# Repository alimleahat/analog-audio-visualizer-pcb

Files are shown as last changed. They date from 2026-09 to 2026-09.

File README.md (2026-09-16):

# Analog Audio Visualizer PCB

A three-band audio visualizer built for **ELEC2101 Electronic Circuits and Systems Design**. It separates audio into bass, midrange, and treble, with an LED responding to each band.

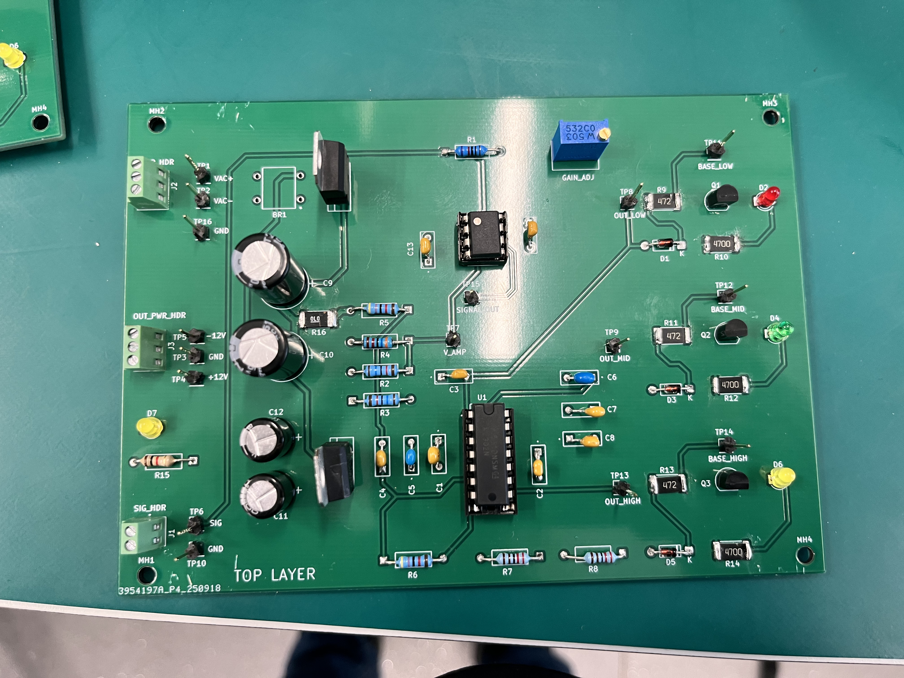
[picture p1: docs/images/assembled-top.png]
Assembled audio visualizer PCB


## My contribution

Following the course guide and reference circuit, I completed the schematic in KiCad, assigned component footprints, laid out and routed the PCB, prepared the manufacturing files, assembled the board, and tested it in the lab.

The project gave me practical experience with analog circuits, two-layer PCB layout, through-hole and surface-mount soldering, and electrical measurements.

## How it works

The audio input passes through an adjustable amplifier, then three filters separate the low, middle, and high frequencies. Transistor circuits drive the corresponding LEDs. The circuit uses LM2904 and LM2902 op-amps and a dual ±12 V supply.

[View the schematic](docs/images/schematic.png) · [View the PCB layout](docs/images/pcb-layout.png)

## Assembly and testing

The board was assembled and tested using a regulated bench supply connected through J3. The recorded supply measurements were **+11.99 V** and **−12.03 V**. The lab checklist records all three LEDs responding to audio and the sensitivity adjustment working.

The bridge rectifier BR1 was unavailable, so the AC-input power-supply section was not tested. The treble LED is yellow instead of the blue LED specified in the design.

[Solder-side photo](docs/images/solder-side.png) · [Surface-mount detail](docs/images/smd-detail.png) · [Measurement photos and test notes](docs/testing.md)

## Open the design

Open [`hardware/audiovisualiser.kicad_pro`](hardware/audiovisualiser.kicad_pro) in **KiCad 9** with the standard symbol and footprint libraries installed. The project includes the editable schematic and PCB layout.

The folders contain:

- **`hardware/`** — KiCad project, schematic, and PCB.
- **`manufacturing/`** — Gerber and drill files for fabrication, a bill of materials, and component positions.
- **`docs/`** — design images, assembly photos, measurements, and design-check reports.

The latest KiCad checks report no electrical or PCB layout violations under the saved rules, and no unconnected items. Four comparison warnings identify mounting holes that appear only on the PCB. Details are in the [testing notes](docs/testing.md).

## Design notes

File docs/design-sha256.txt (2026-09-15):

d43a5ad52d6238cfd297c0390aba6e84c12491bfbb42c92468e123850f972aae  hardware/audiovisualiser.kicad_pcb
11a3e94168e5f908d9af25af031c0f9f0a650db64b1d5642f39403e3dbae1e51  hardware/audiovisualiser.kicad_pro
699c0b7c9d165394a2f6ad1a235572f3e88ec57767753e0e1b9193906fe388a9  hardware/audiovisualiser.kicad_sch
56e890d3f30cbfee17a181a69a6859d38080b0e7b6440230e2523ef3031b595b  manufacturing/gerbers/audiovisualiser-B_Cu.gbr
b3edec788258d4f6de82463fa68dd532487a897ee7c1164198f9244877f3723b  manufacturing/gerbers/audiovisualiser-B_Mask.gbr
3db5783e143c3a7090b456dbd70b5f65db10d94b7363bcfdbad7da6e1dbb668b  manufacturing/gerbers/audiovisualiser-B_Silkscreen.gbr
cdbf6ed5389bc9ae697716cc27e2d69105f45a44620da87fb1bf32727c460968  manufacturing/gerbers/audiovisualiser-Edge_Cuts.gbr
14875b5e7e3f8ffb195601ec47e5f753f74b633e8d50d9912a69eebf286eb574  manufacturing/gerbers/audiovisualiser-F_Cu.gbr
0dd54d515c6167a6fd7fc06f26bf98b8b54d1db28c1bfb878f05ad543f4662b6  manufacturing/gerbers/audiovisualiser-F_Mask.gbr
acfe5b5dd1af43d6daa099b551af098ea3adf2971c16712e91b3fa432e4e91e0  manufacturing/gerbers/audiovisualiser-F_Silkscreen.gbr
f37c09cf444785ee8dca576edfb6f33e4edd3a44a8568f85b55a7a8c0175424d  manufacturing/gerbers/audiovisualiser-NPTH.drl
87c2988971aea0b9ab081e4a7189159ee5fceac178d744cfe9fef5f88cfd54ae  manufacturing/gerbers/audiovisualiser-PTH.drl
732ebaa7cd275ef8b9e11f3401f31154eaca13fc0503ec177f53244ad57ac680  manufacturing/gerbers/audiovisualiser-job.gbrjob
2de11d1e49a75330ba2134e22420dceb4e55c76b61dfe5de430449ad1b904d96  manufacturing/bill-of-materials.csv
264a6dbcaaf517e89931273f5c0e9ae222f43909895c9295ed0664edde9b2d73  manufacturing/component-positions.csv

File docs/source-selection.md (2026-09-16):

# Source selection

## Selected design

The working `audiovisualiser` directory, the Week 4 submission, and `AudioVisualiserFiles` contain byte-identical schematic and PCB files. The working directory also contains the matching KiCad project settings, which are included so the saved design rules travel with the schematic and board.

The seven Gerber files match the Week 4 production archive byte-for-byte. Plated and non-plated drill files, the Gerber job file, the BOM, and component positions come from the same working project. Manufacturing files are historical exports; they were not regenerated during portfolio preparation.

## Selected build evidence

The extracted Week 11 folder matches the final Week 11 ZIP. The archive with the `2.zip` suffix differs in its README and test checklist; the final extracted folder was used because it includes the explicit BR1 omission and bench-supply test qualification.

Three assembly images were extracted from the final assembly-photo PDF. The power-on and positive/negative rail photos come from the final testing folder. Image content is preserved.

## Excluded material

Videos, duplicate submission archives, autosaves, backup ZIPs, local KiCad state, repeated photo PDFs, and student-number submission filenames are omitted. The original test checklist contains general instructions and a broad pass statement that could obscure the untested AC power path; its relevant outcomes are summarized in `testing.md`.

The course manual and supplied reference PDF were used to establish project context. They are not republished. The public schematic is the author's KiCad capture of the guided reference design.

## Original files

The source archive remains untouched. Project files, manufacturing exports, and selected standalone images were copied; assembly photos were extracted from the existing PDF. Documentation and new KiCad check reports were added for this repository.

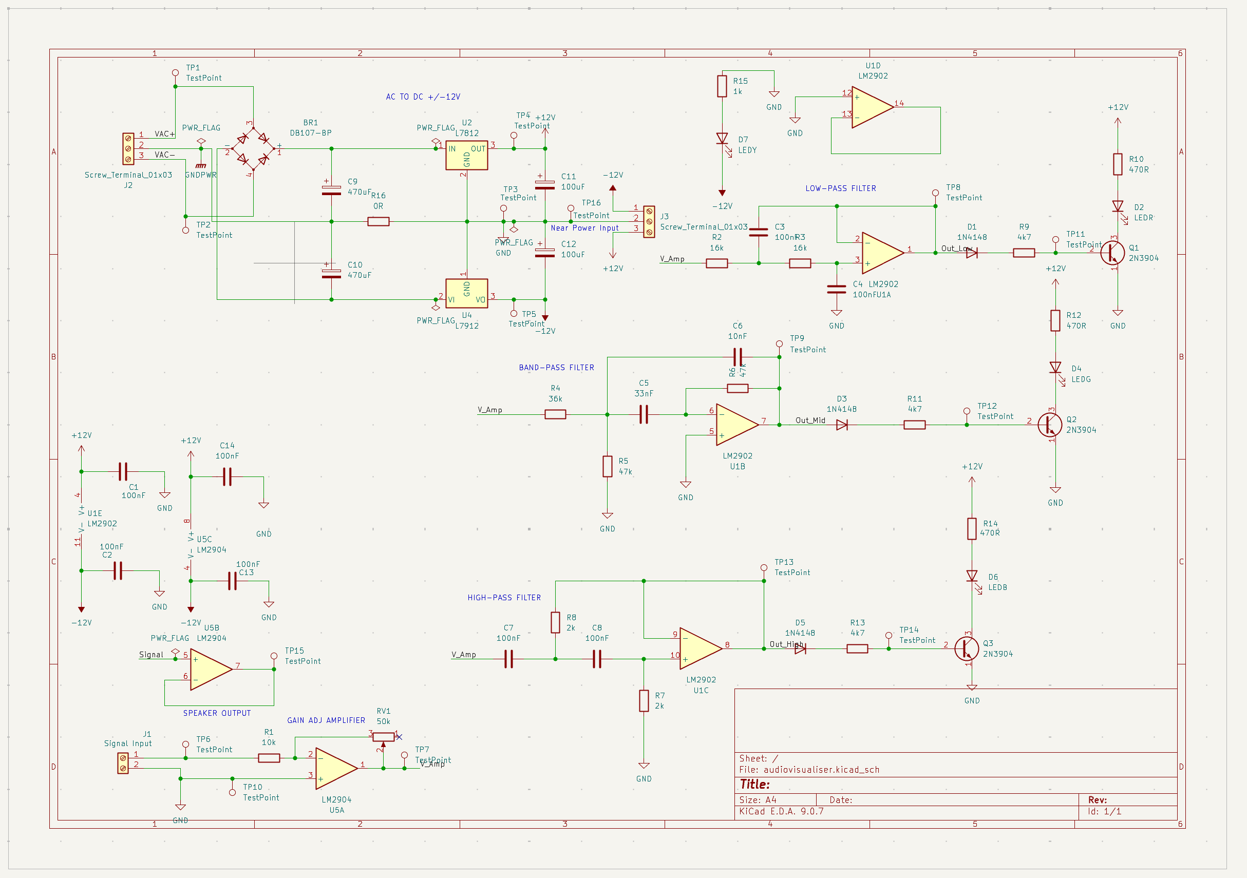
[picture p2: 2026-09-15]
docs/images/schematic.png

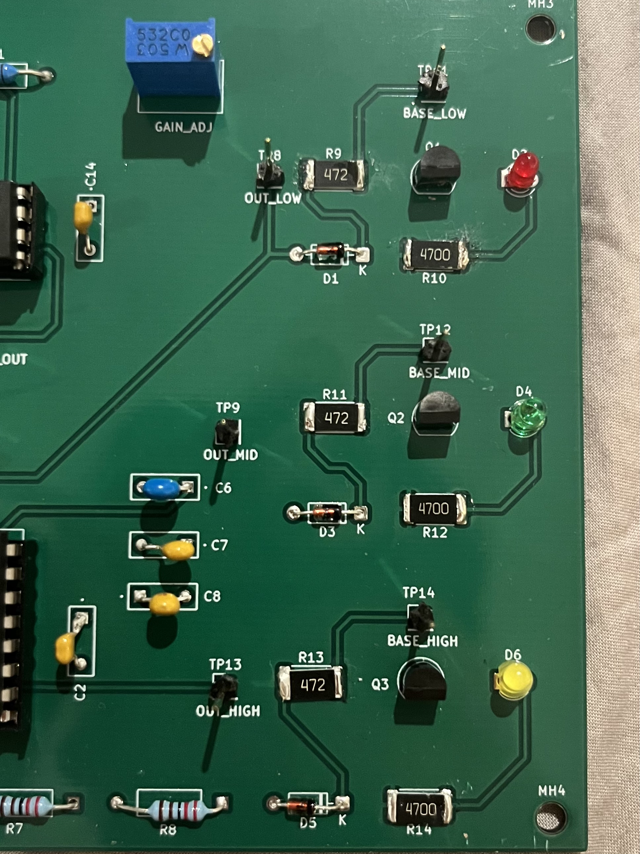
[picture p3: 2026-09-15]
docs/images/smd-detail.png

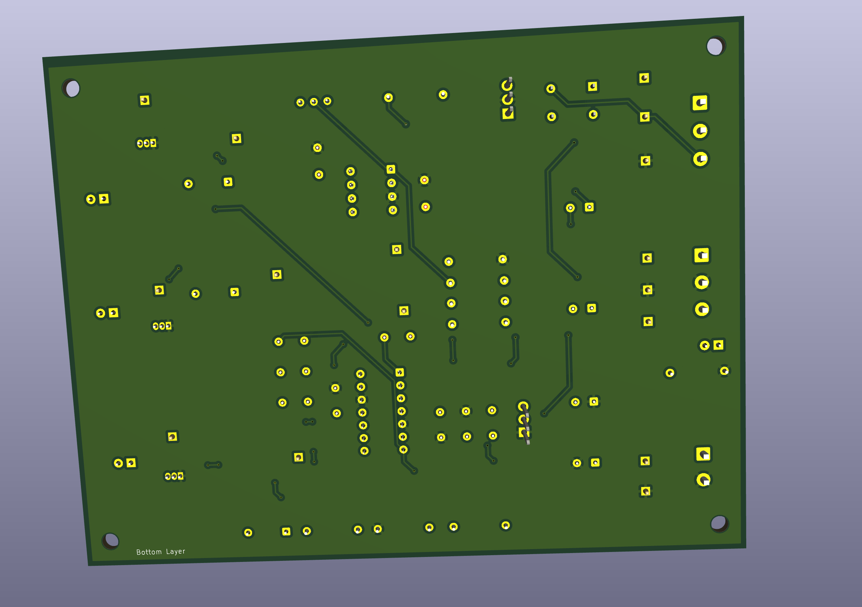
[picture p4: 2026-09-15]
docs/images/pcb-3d-bottom.png

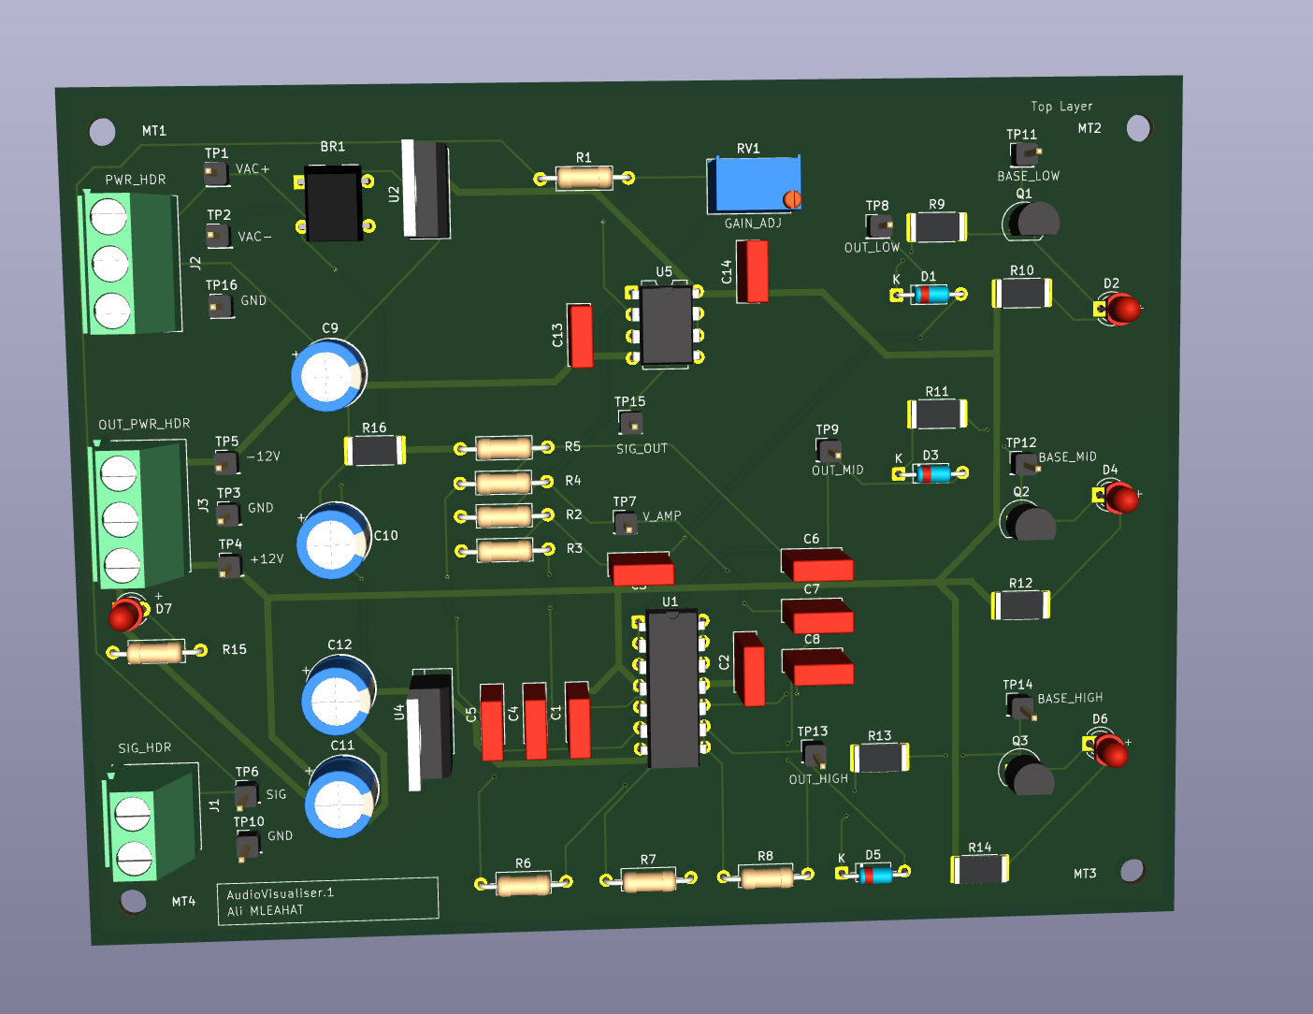
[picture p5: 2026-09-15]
docs/images/pcb-3d-top.png

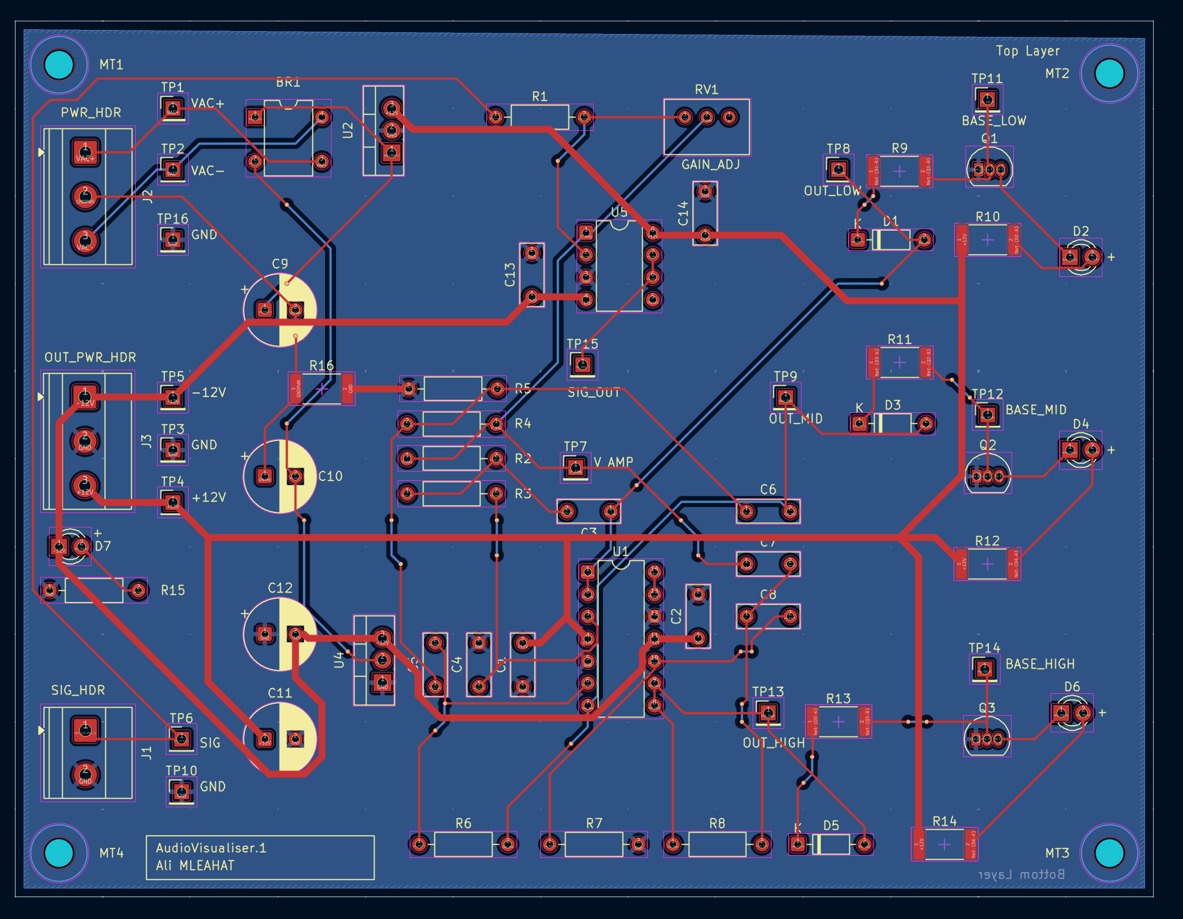
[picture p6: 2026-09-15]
docs/images/pcb-layout.png

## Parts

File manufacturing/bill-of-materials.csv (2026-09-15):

Reference | Qty | Value | Footprint
BR1 | 1 | DB107-BP | Diode_THT:Diode_Bridge_DIP-4_W7.62mm_P5.08mm
C1,C2,C3,C4,C7,C8,C13,C14 | 8 | 100nF | Capacitor_THT:C_Rect_L7.0mm_W2.5mm_P5.00mm
C5 | 1 | 33nF | Capacitor_THT:C_Rect_L7.0mm_W2.5mm_P5.00mm
C6 | 1 | 10nF | Capacitor_THT:C_Rect_L7.0mm_W2.5mm_P5.00mm
C9,C10 | 2 | 470uF | Capacitor_THT:CP_Radial_D8.0mm_P3.50mm
C11,C12 | 2 | 100uF | Capacitor_THT:CP_Radial_D8.0mm_P3.50mm
D1,D3,D5 | 3 | 1N4148 | Diode_THT:D_DO-35_SOD27_P7.62mm_Horizontal
D2 | 1 | LEDR | LED_THT:LED_D3.0mm
D4 | 1 | LEDG | LED_THT:LED_D3.0mm
D6 | 1 | LEDB | LED_THT:LED_D3.0mm
D7 | 1 | LEDY | LED_THT:LED_D3.0mm
J1 | 1 | Signal Input | TerminalBlock_Phoenix:TerminalBlock_Phoenix_MKDS-1,5-2-5.08_1x02_P5.08mm_Horizontal
J2,J3 | 2 | Screw_Terminal_01x03 | TerminalBlock_Phoenix:TerminalBlock_Phoenix_MKDS-1,5-3-5.08_1x03_P5.08mm_Horizontal
Q1,Q2,Q3 | 3 | 2N3904 | Package_TO_SOT_THT:TO-92_Inline
R1 | 1 | 10k | Resistor_THT:R_Axial_DIN0207_L6.3mm_D2.5mm_P10.16mm_Horizontal
R2,R3 | 2 | 16k | Resistor_THT:R_Axial_DIN0207_L6.3mm_D2.5mm_P10.16mm_Horizontal
R4 | 1 | 36k | Resistor_THT:R_Axial_DIN0207_L6.3mm_D2.5mm_P10.16mm_Horizontal
R5,R6 | 2 | 47k | Resistor_THT:R_Axial_DIN0207_L6.3mm_D2.5mm_P10.16mm_Horizontal
R7,R8 | 2 | 2k | Resistor_THT:R_Axial_DIN0207_L6.3mm_D2.5mm_P10.16mm_Horizontal
R9,R11,R13 | 3 | 4k7 | Resistor_SMD:R_2512_6332Metric
R10,R12,R14 | 3 | 470R | Resistor_SMD:R_2512_6332Metric
R15 | 1 | 1k | Resistor_THT:R_Axial_DIN0207_L6.3mm_D2.5mm_P10.16mm_Horizontal
R16 | 1 | 0R | Resistor_SMD:R_2512_6332Metric
RV1 | 1 | 50k | Potentiometer_THT:Potentiometer_Bourns_3299W_Vertical
TP1,TP2,TP3,TP4,TP5,TP6,TP7,TP8,TP9,TP10,TP11,TP12,TP13,TP14,TP15,TP16 | 16 | TestPoint | Connector_PinHeader_2.54mm:PinHeader_1x01_P2.54mm_Vertical
U1 | 1 | LM2902 | Package_DIP:DIP-14_W7.62mm
U2 | 1 | L7812 | Package_TO_SOT_THT:TO-220-3_Vertical
U4 | 1 | L7912 | Package_TO_SOT_THT:TO-220-3_Vertical
U5 | 1 | LM2904 | Package_DIP:DIP-8_W7.62mm

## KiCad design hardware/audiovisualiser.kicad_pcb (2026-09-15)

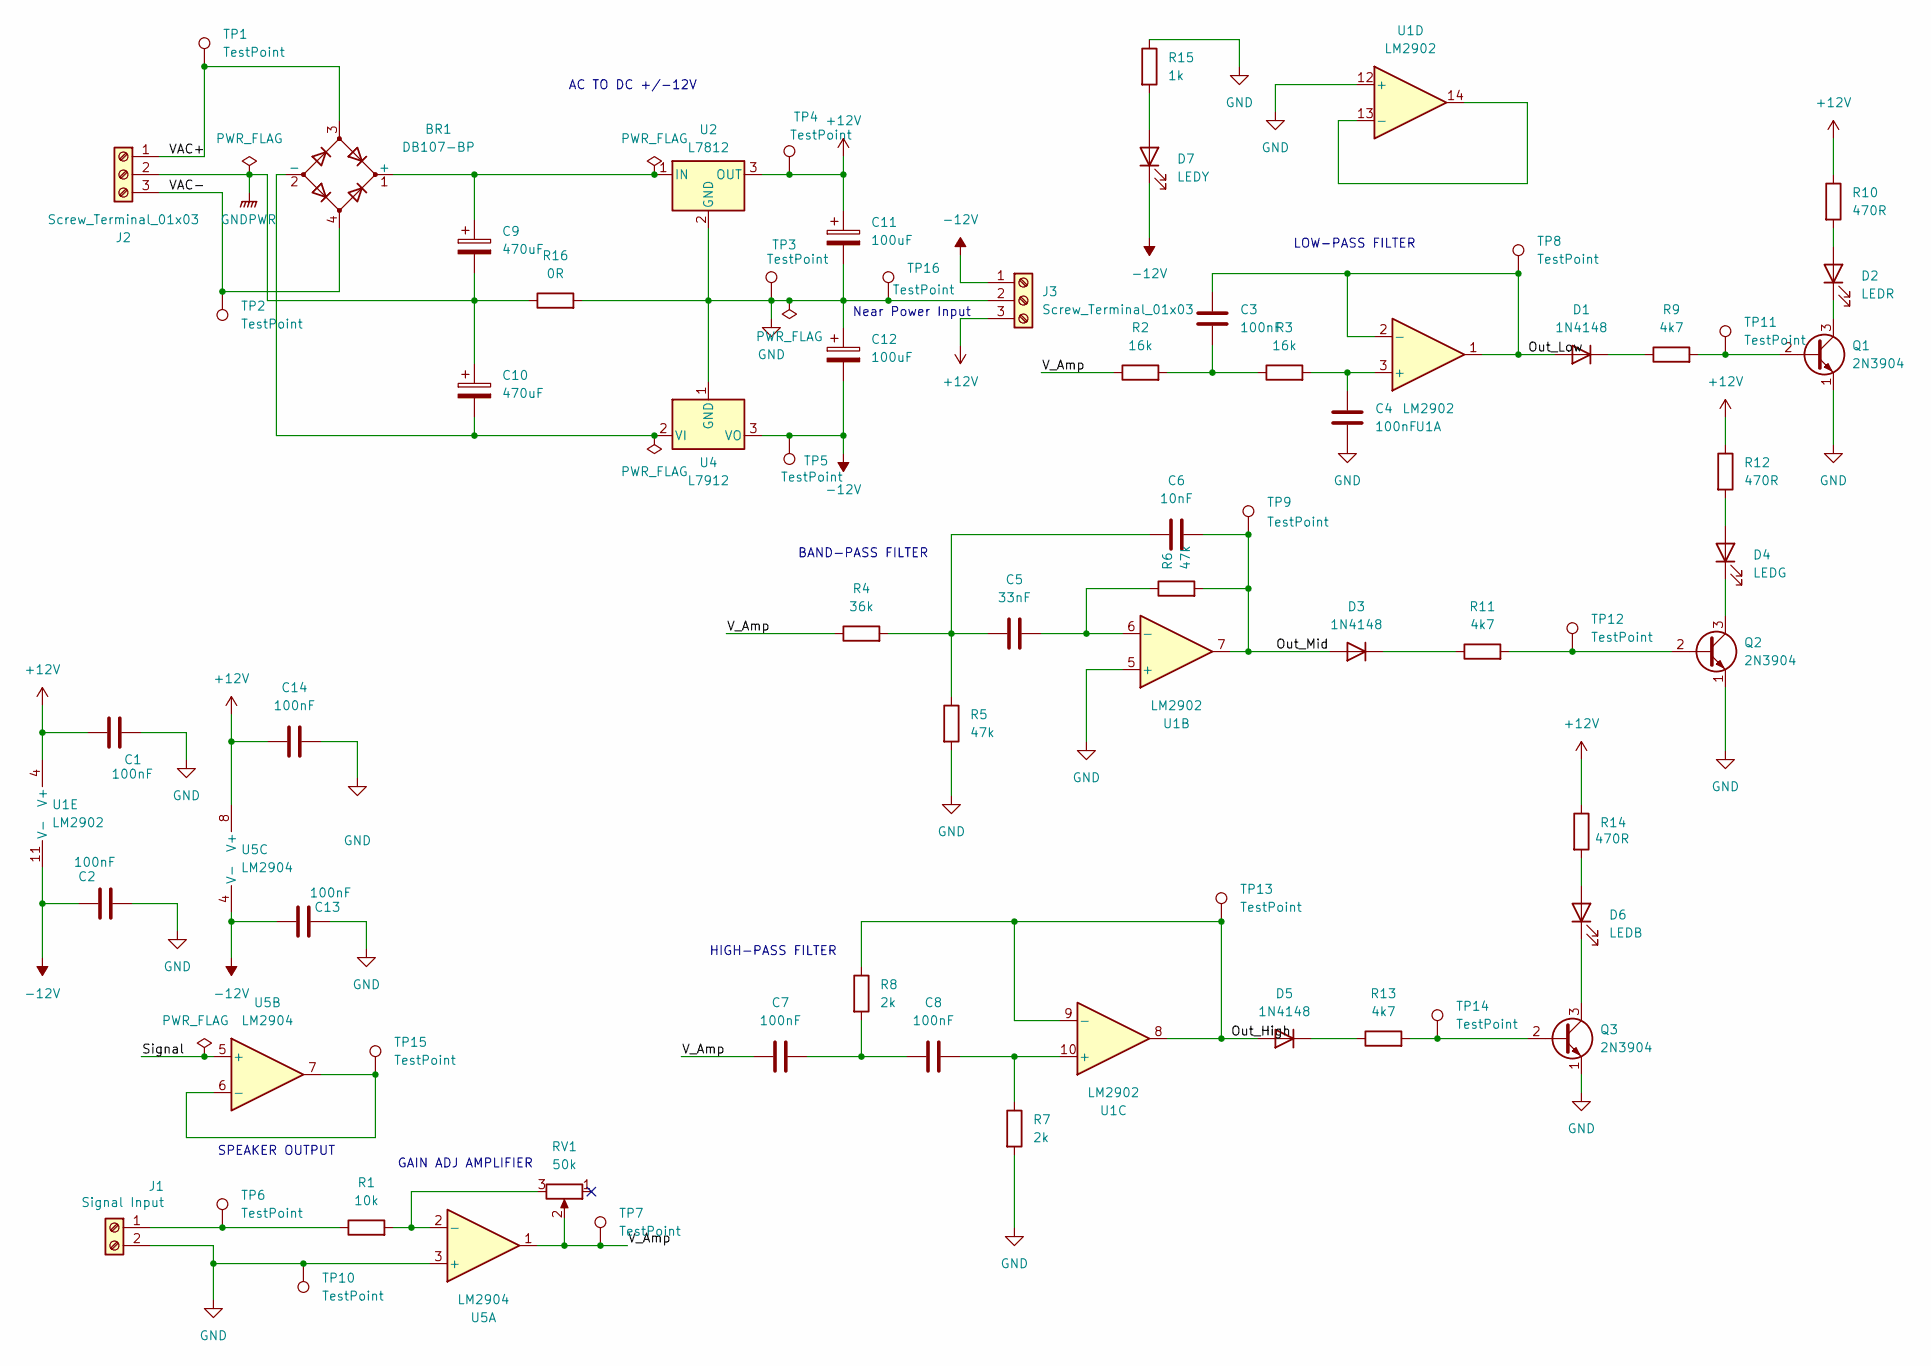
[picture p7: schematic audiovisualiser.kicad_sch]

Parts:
BR1: DB107-BP; Diode_Bridge_DIP-4_W7.62mm_P5.08mm
C1, C2, C3, C4, C7, C8, C13, C14: 100nF; C_Rect_L7.0mm_W2.5mm_P5.00mm
C5: 33nF; C_Rect_L7.0mm_W2.5mm_P5.00mm
C6: 10nF; C_Rect_L7.0mm_W2.5mm_P5.00mm
C9, C10: 470uF; CP_Radial_D8.0mm_P3.50mm
C11, C12: 100uF; CP_Radial_D8.0mm_P3.50mm
D1, D3, D5: 1N4148; D_DO-35_SOD27_P7.62mm_Horizontal
D2: LEDR; LED_D3.0mm
D4: LEDG; LED_D3.0mm
D6: LEDB; LED_D3.0mm
D7: LEDY; LED_D3.0mm
J1: Signal Input; TerminalBlock_Phoenix_MKDS-1,5-2-5.08_1x02_P5.08mm_Horizont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
J2, J3: Screw_Terminal_01x03; TerminalBlock_Phoenix_MKDS-1,5-3-5.08_1x03_P5.08mm_Horizont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
Q1, Q2, Q3: 2N3904; TO-92_Inline
R1: 10k; R_Axial_DIN0207_L6.3mm_D2.5mm_P10.16mm_Horizontal
R2, R3: 16k; R_Axial_DIN0207_L6.3mm_D2.5mm_P10.16mm_Horizontal
R4: 36k; R_Axial_DIN0207_L6.3mm_D2.5mm_P10.16mm_Horizontal
R5, R6: 47k; R_Axial_DIN0207_L6.3mm_D2.5mm_P10.16mm_Horizontal
R7, R8: 2k; R_Axial_DIN0207_L6.3mm_D2.5mm_P10.16mm_Horizontal
R9, R11, R13: 4k7; R_2512_6332Metric
R10, R12, R14: 470R; R_2512_6332Metric
R15: 1k; R_Axial_DIN0207_L6.3mm_D2.5mm_P10.16mm_Horizontal
R16: 0R; R_2512_6332Metric
RV1: 50k; Potentiometer_Bourns_3299W_Vertical
TP1, TP2, TP3, TP4, TP5, TP6, TP7, TP8, TP9, TP10, TP11, TP12, TP13, TP14, TP15, TP16: TestPoint; PinHeader_1x01_P2.54mm_Vertical
U1: LM2902; DIP-14_W7.62mm
U2: L7812; TO-220-3_Vertical
U4: L7912; TO-220-3_Vertical
U5: LM2904; DIP-8_W7.62mm

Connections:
+12V: C1.2, C11.1, C14.1, J3.3, R10.1, R12.1, R14.1, TP4.1, U1.4 (V+), U2.3 (OUT), U5.8 (V+)
-12V: C2.1, C12.2, C13.1, D7.1 (K), J3.1, TP5.1, U1.11 (V-), U4.3 (VO), U5.4 (V-)
/Out_High: D5.2 (A), R8.1, TP13.1, U1.8, U1.9 (-)
/Out_Low: C3.1, D1.2 (A), TP8.1, U1.1, U1.2 (-)
/Out_Mid: C6.2, D3.2 (A), R6.2, TP9.1, U1.7
/Signal: U5.5 (+)
/VAC+: BR1.3, J2.1, TP1.1
/VAC-: BR1.4, J2.3, TP2.1
/V_Amp: C7.1, R2.1, R4.1, RV1.2, TP7.1, U5.1
GND: C1.1, C2.2, C4.2, C11.2, C12.1, C13.2, C14.2, J1.2, J3.2, Q1.1 (E), Q2.1 (E), Q3.1 (E), R5.2, R7.2, R15.1, R16.2, TP3.1, TP10.1, TP16.1, U1.5 (+), U1.12 (+), U2.2 (GND), U4.1 (GND), U5.3 (+)
GNDPWR: C9.2, C10.1, J2.2, R16.1
unnamed: BR1.1 (+), C9.1, U2.1 (IN)
unnamed: BR1.2 (-), C10.2, U4.2 (VI)
unnamed: C3.2, R2.2, R3.1
unnamed: C5.1, C6.1, R4.2, R5.1
unnamed: C7.2, C8.1, R8.2
unnamed: D1.1 (K), R9.1
unnamed: D2.2 (A), R10.2
unnamed: D2.1 (K), Q1.3 (C)
unnamed: D3.1 (K), R11.1
unnamed: D4.2 (A), R12.2
unnamed: D4.1 (K), Q2.3 (C)
unnamed: D5.1 (K), R13.1
unnamed: D6.2 (A), R14.2
unnamed: D6.1 (K), Q3.3 (C)
unnamed: D7.2 (A), R15.2
unnamed: J1.1, R1.1, TP6.1
unnamed: Q1.2 (B), R9.2, TP11.1
unnamed: Q2.2 (B), R11.2, TP12.1
unnamed: Q3.2 (B), R13.2, TP14.1
unnamed: C4.1, R3.2, U1.3 (+)
unnamed: C5.2, R6.1, U1.6 (-)
unnamed: C8.2, R7.1, U1.10 (+)
unnamed: U1.13 (-), U1.14
unnamed: R1.2, RV1.3, U5.2 (-)
unnamed: TP15.1, U5.6 (-), U5.7

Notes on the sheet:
SPEAKER OUTPUT
Near Power Input
GAIN ADJ AMPLIFIER
AC TO DC +/-12V
HIGH-PASS FILTER
BAND-PASS FILTER
LOW-PASS FILTER

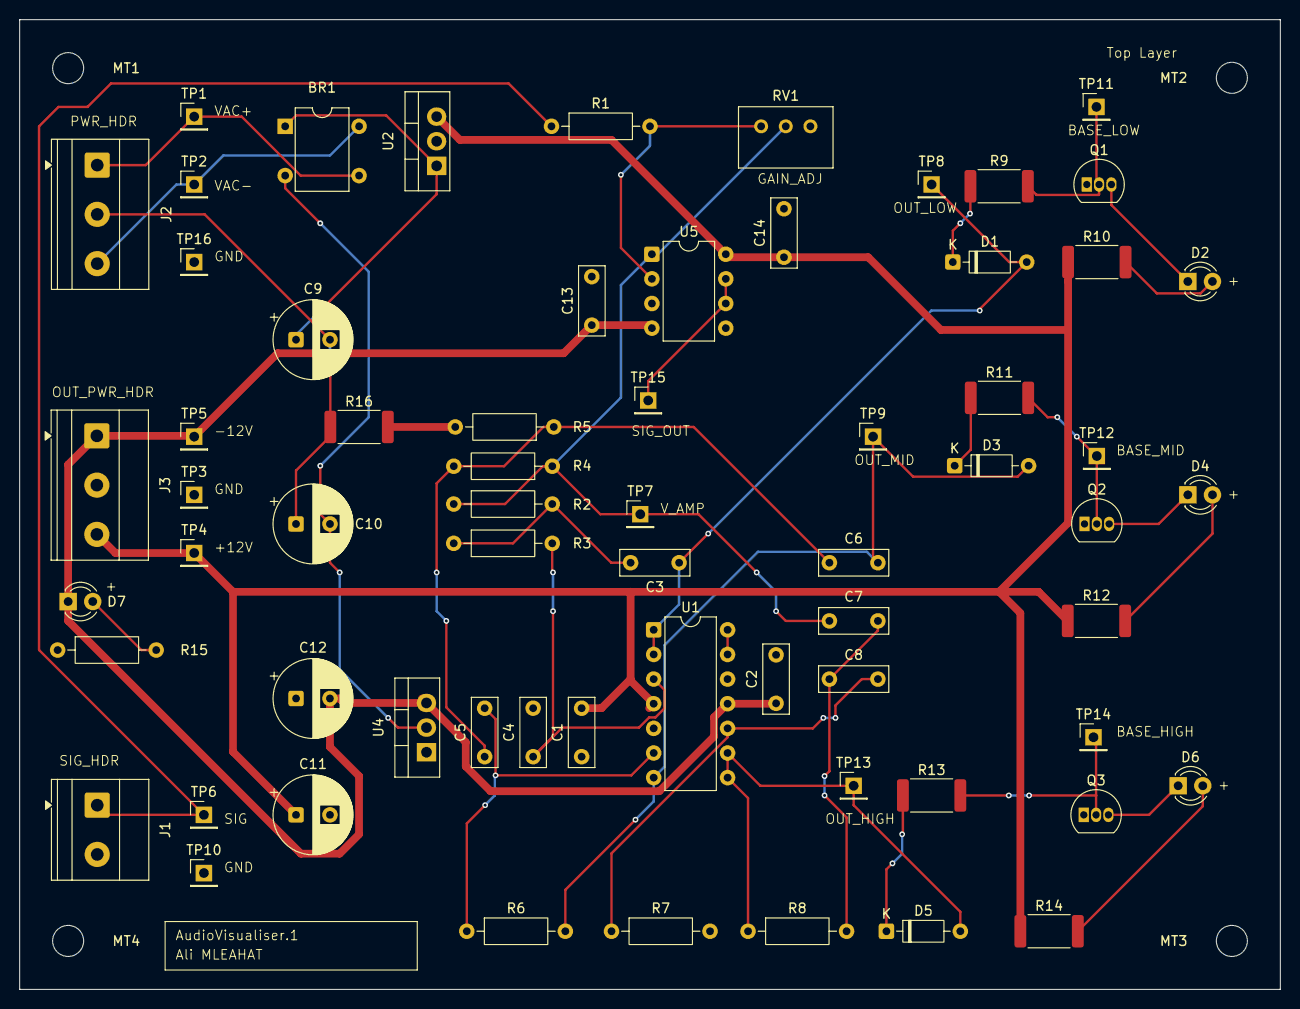
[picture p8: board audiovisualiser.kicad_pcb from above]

Board: 2 copper layers, 130.0 x 100.0 mm, 69 parts (0 on the bottom side), 35 nets.

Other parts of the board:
MT1, MT2, MT3, MT4: MountingHole_3.2mm_M3

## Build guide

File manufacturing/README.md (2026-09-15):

# Manufacturing outputs

These are the original project exports, retained as build evidence:

- `gerbers/`: seven layers covering front/back copper, front/back solder mask, front/back silkscreen, and the board outline.
- `gerbers/audiovisualiser-PTH.drl`: plated component holes.
- `gerbers/audiovisualiser-NPTH.drl`: non-plated mounting holes.
- `gerbers/audiovisualiser-job.gbrjob`: layer manifest and fabrication metadata.
- `bill-of-materials.csv`: reference designators, quantities, values, and footprints.
- `component-positions.csv`: original placement export.

The design BOM includes BR1 and a blue D6. The demonstrated build omitted BR1 and substituted a yellow D6; see the testing notes. These files have not been regenerated or requalified for a new production order. Open the Gerbers and drills together in KiCad Gerber Viewer before using them.

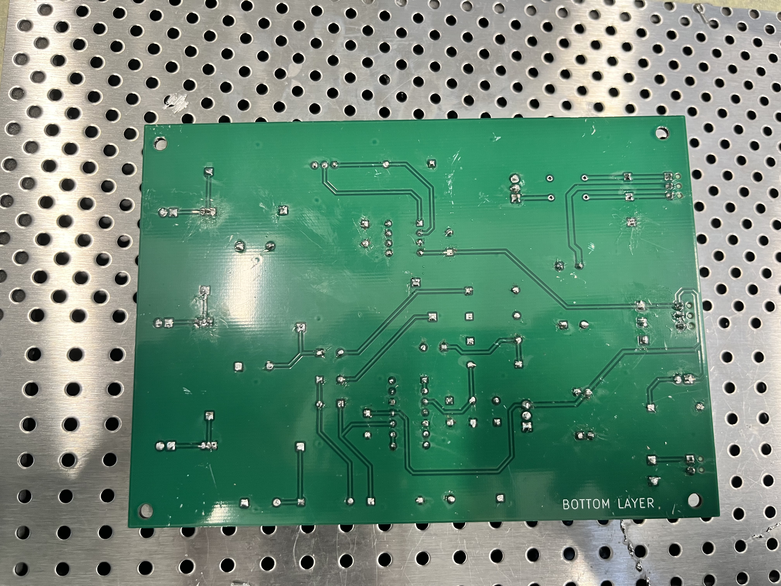
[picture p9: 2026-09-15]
docs/images/solder-side.png

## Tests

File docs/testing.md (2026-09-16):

# Testing and validation

## Bench configuration

The assembly was powered from a regulated dual bench supply through J3, using the board's +12 V, GND, and −12 V connections. BR1 (DB107-BP) was unavailable and was not fitted. The AC-input path through J2, BR1, the reservoir capacitors, and the regulators was not tested. The recorded rail voltages therefore demonstrate the externally supplied rails, not regulator performance.

D6, the treble indicator, was fitted with a yellow LED instead of the blue LED listed in the design BOM. These deviations are recorded in the final Week 11 submission notes.

## Recorded measurements

- TP4, positive rail: **+11.99 V**.
- TP5, negative rail: **−12.03 V**.
- The original checklist also records small no-input DC offsets at the amplifier and filter outputs, and successful LED response and sensitivity-adjustment checks.

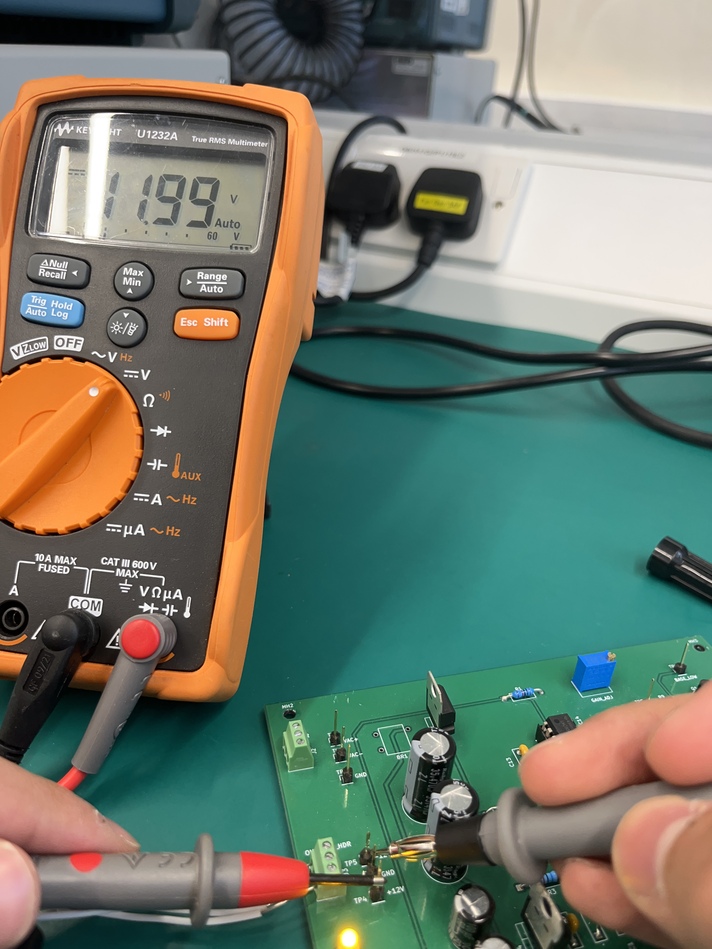
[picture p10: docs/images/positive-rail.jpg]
Positive rail measurement


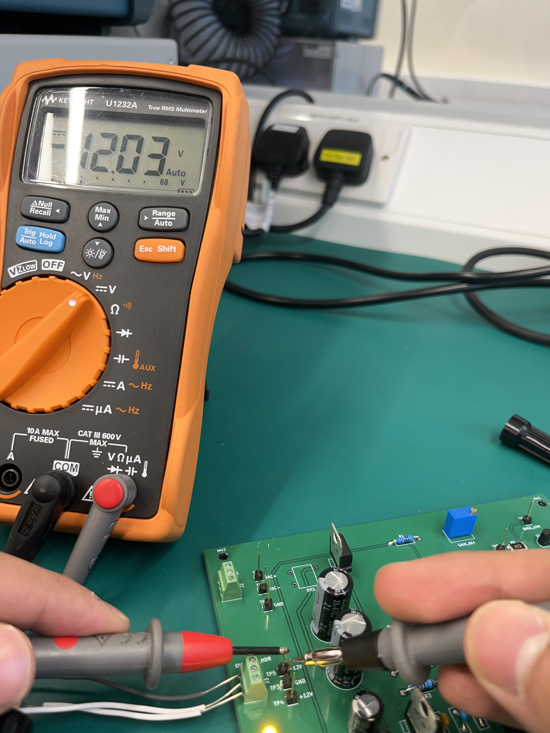
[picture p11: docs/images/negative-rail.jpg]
Negative rail measurement


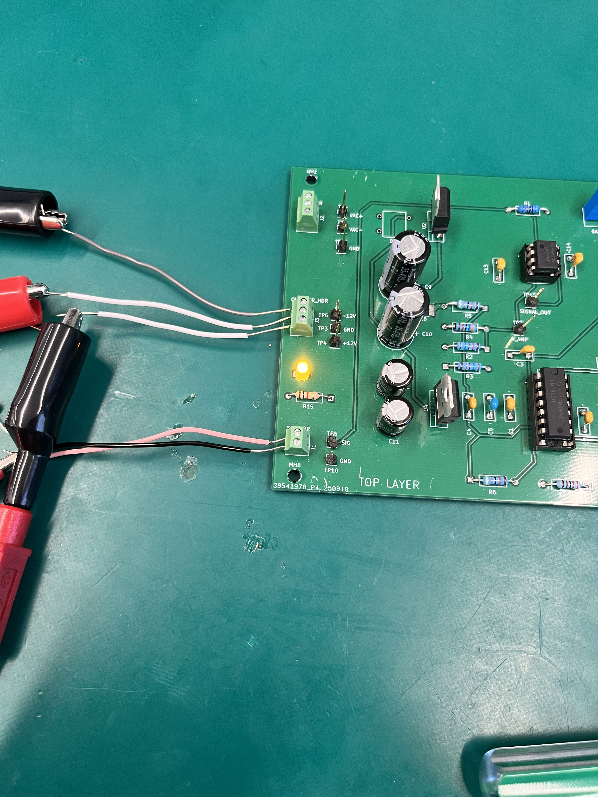
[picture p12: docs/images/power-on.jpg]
Power-on configuration


The photos are original bench evidence. The operating measurements have not been repeated during repository preparation. The broad “all tests passed” wording in the original checklist is not used here because the AC power path was explicitly untested.

## KiCad checks

The preserved project was checked using KiCad 9.0.7 on 15 September 2026:

- [Electrical-rule report](validation/current-erc.json): no reported violations.
- [PCB-rule and schematic-parity report](validation/current-drc.json): no reported layout violations, no unconnected items, and four extra-footprint warnings for mounting holes MT1–MT4.

The four mounting footprints are `MountingHole_3.2mm_M3` mechanical features placed directly on the PCB. They have no corresponding schematic symbols. No circuit connectivity mismatch was reported.

Checks use the project's saved rule severities; some rule categories are configured to be ignored. The archived [ERC screenshot](validation/original-erc.png) shows four ignored tests; the archived [DRC screenshot](validation/original-drc.png) shows five and did not run schematic parity. The current reports are provided alongside them for clarity.

## Validation limits

The evidence does not include a swept frequency-response measurement, quantified distortion/noise, measured cutoff tolerances, or verification of the AC-to-DC power path. The checklist records functional testing; it does not establish complete analog performance characterization.
